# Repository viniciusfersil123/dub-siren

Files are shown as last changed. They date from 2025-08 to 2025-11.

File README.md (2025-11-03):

### Knobs (ADC)
| Function | Daisy Seed Pin | ADC Channel |
|---|---|---|
| Volume | 22 (A0) | VolumeKnob  |
| Decay | 23 (A1) | DecayKnob |
| Depth | 24 (A2) | DepthKnob |
| Tune | 25 (A3) | TuneKnob |
| Sweep | 26 (A4) | SweepKnob |
| Rate | 27 (A5) | RateKnob |

### Buttons (Digital)
| Function | Daisy Seed Pin | Notes |
|---|---|---|
| Trigger 1 | 28 (D21) | Momentary |
| Trigger 2 | 29 (D22) | Momentary |
| Trigger 3 | 30 (D23) | Momentary |
| Trigger 4 | 31 (D24) | Momentary |
| Bank Select | 32 (D25) | Toggle button |
| Sweep to Tune | 33 (D26) | Toggle button |

### LEDs
| Function | Daisy Seed Pin |
|---|---|
| Sweep LED  | D27 |
| Bank LED | D28 |
| LFO LED | D29 |

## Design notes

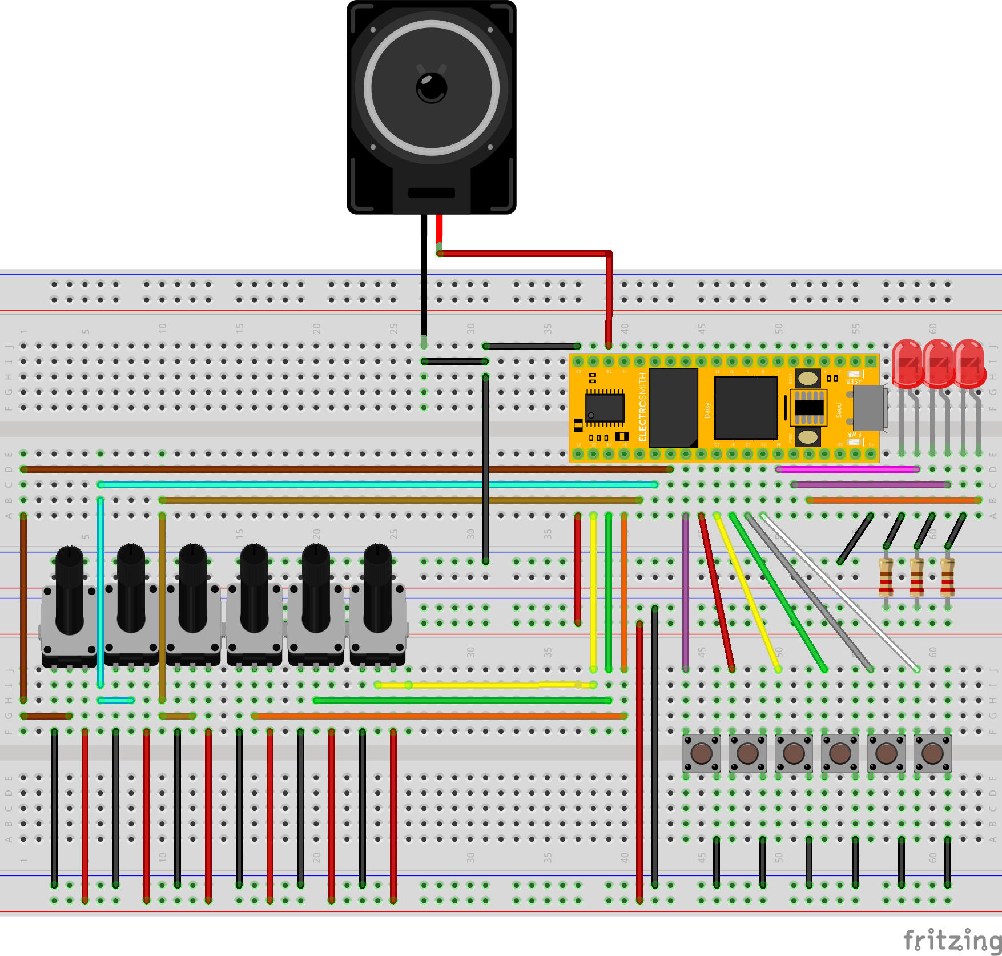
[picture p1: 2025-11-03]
assets/fritzing/dub_siren_Steckplatine.png

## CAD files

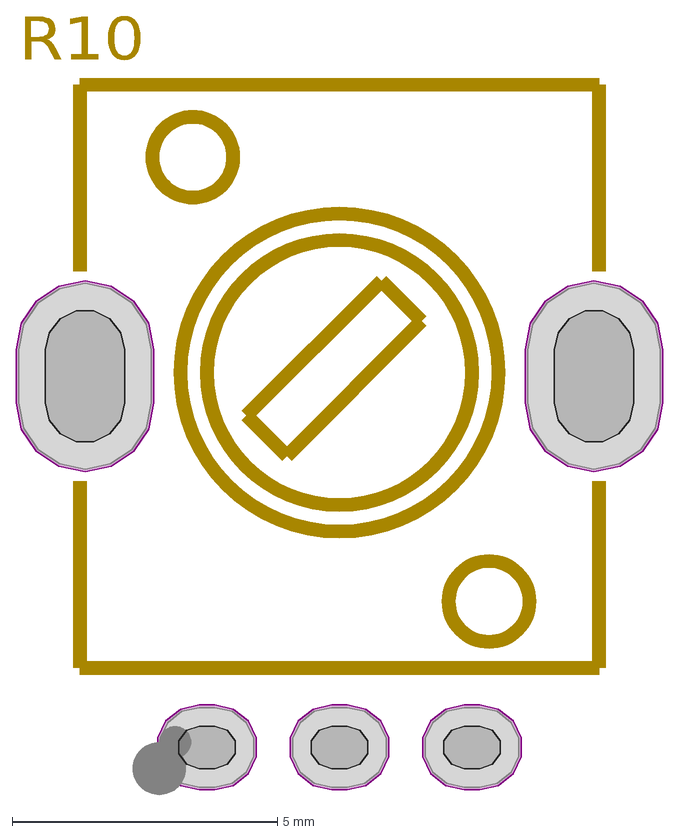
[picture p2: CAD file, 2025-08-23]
assets/footprints/potênciometro.dxf
R10

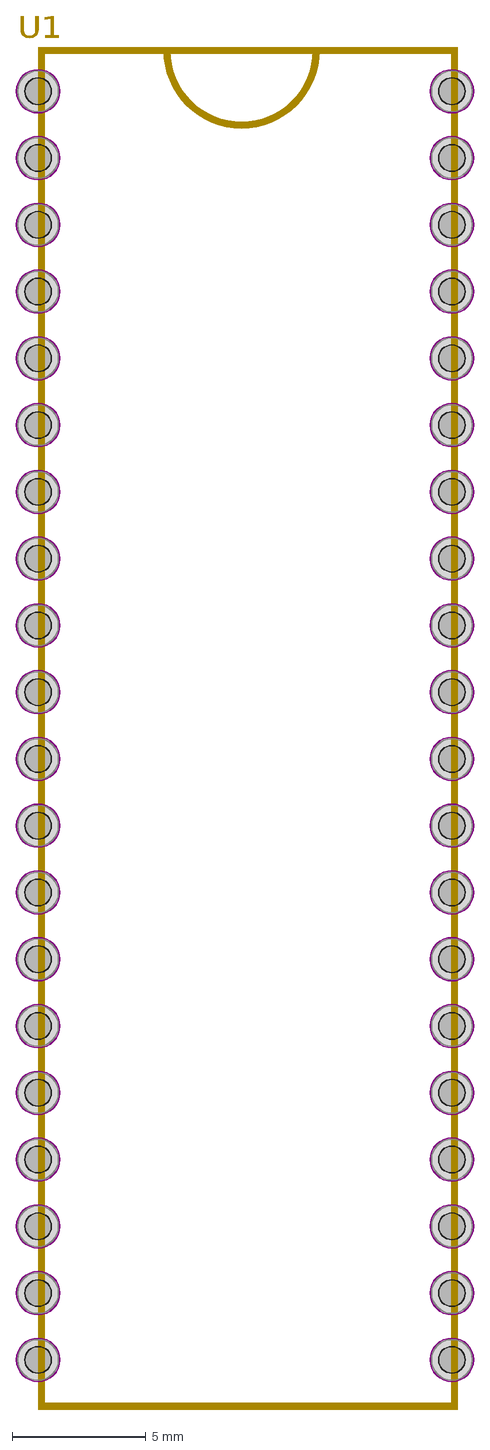
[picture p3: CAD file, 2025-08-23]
assets/footprints/ci.dxf
U1

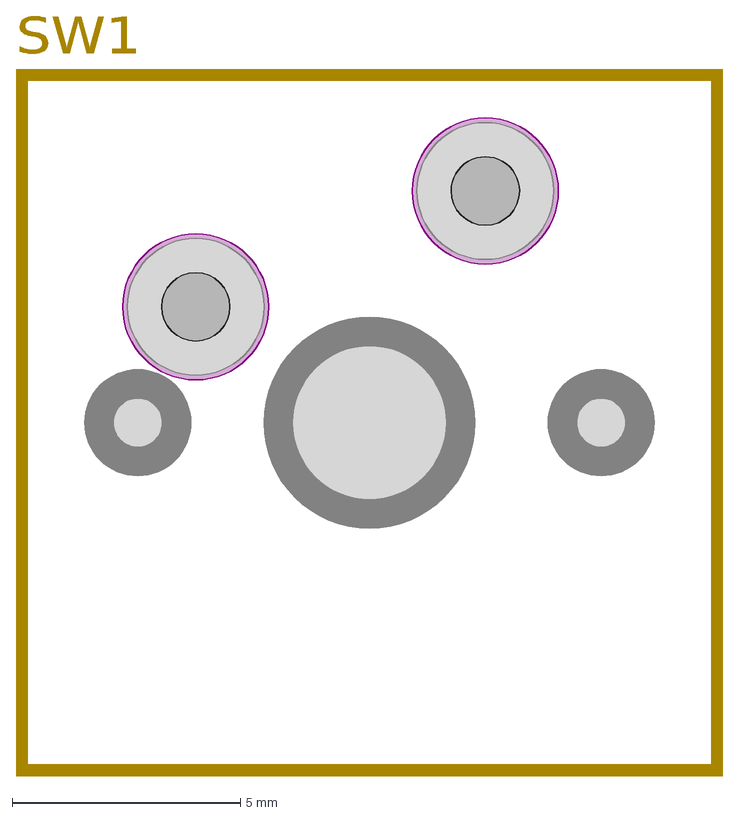
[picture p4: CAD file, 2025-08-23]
assets/footprints/botão.dxf
SW1

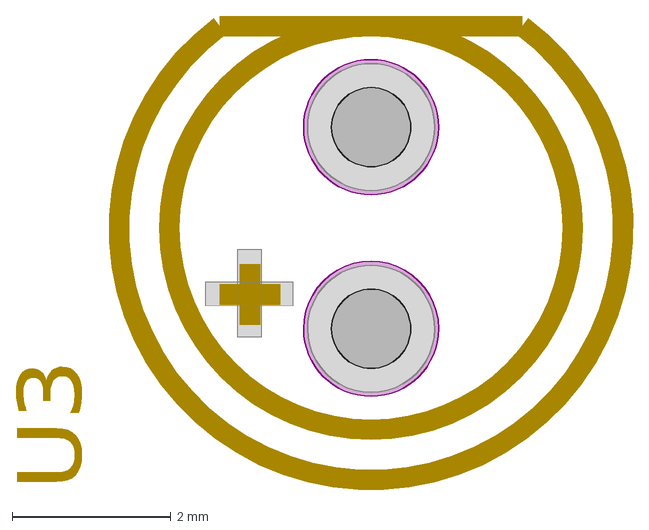
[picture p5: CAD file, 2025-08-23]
assets/footprints/led.dxf
U3

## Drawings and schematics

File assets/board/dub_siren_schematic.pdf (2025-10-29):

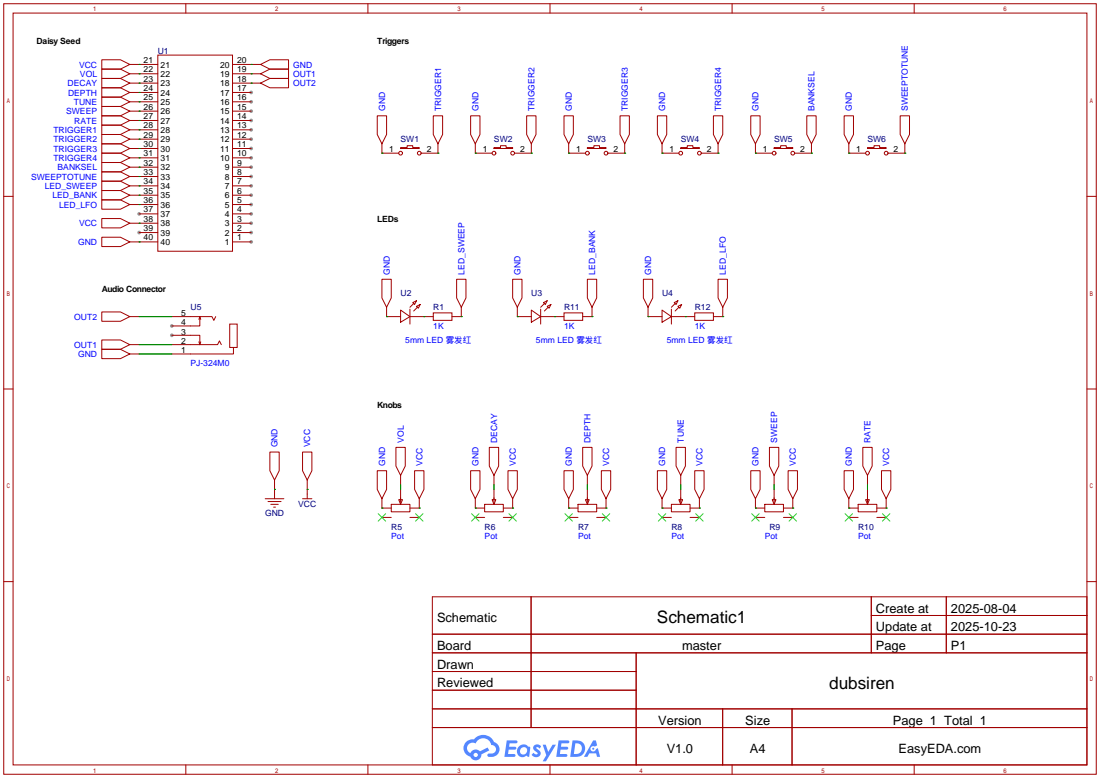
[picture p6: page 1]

Schematic | Schematic1 | Create at | 2025-08-04

Update at | 2025-10-23

Board | master | Page | P1
Drawn | | dubsiren
Reviewed

Version | Size | Page 1 Total 1
V1.0 | A4 | EasyEDA.com

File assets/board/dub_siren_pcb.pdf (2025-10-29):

# adiciona texto

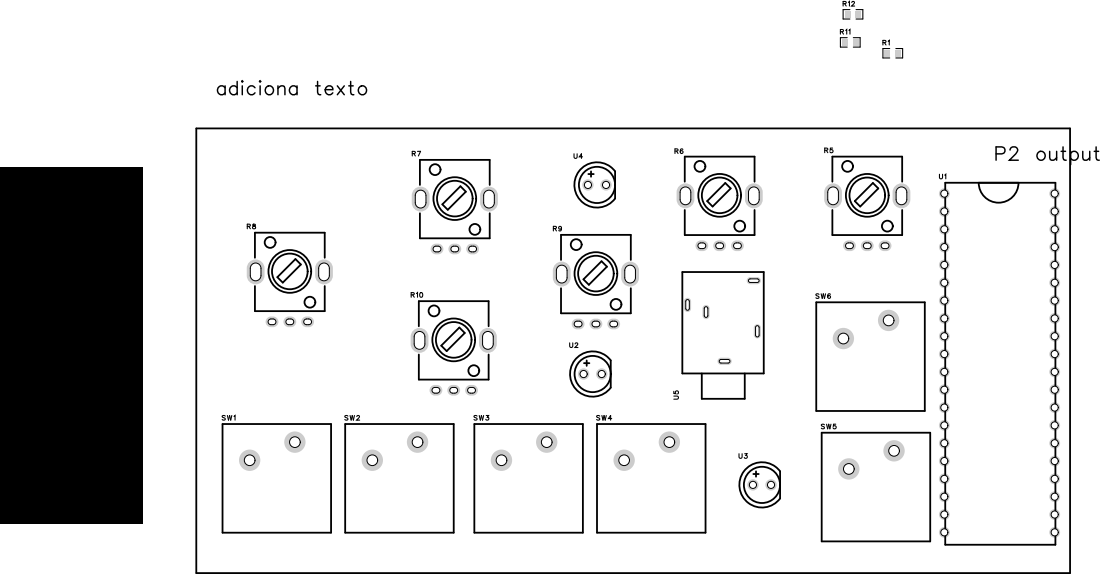
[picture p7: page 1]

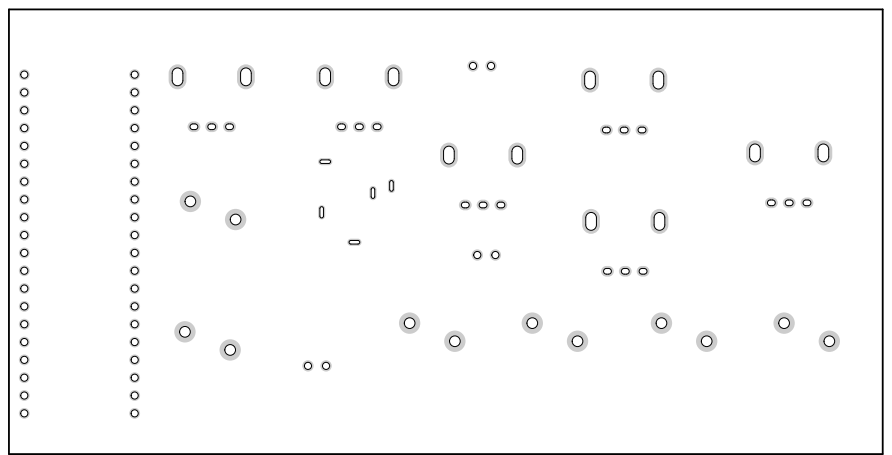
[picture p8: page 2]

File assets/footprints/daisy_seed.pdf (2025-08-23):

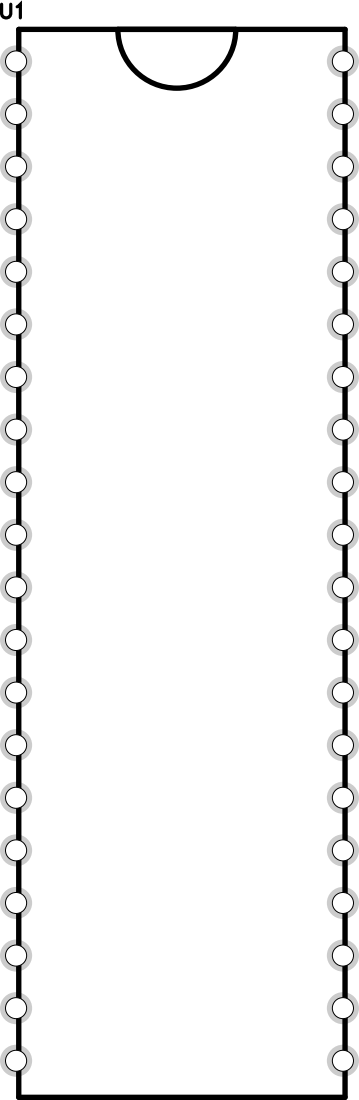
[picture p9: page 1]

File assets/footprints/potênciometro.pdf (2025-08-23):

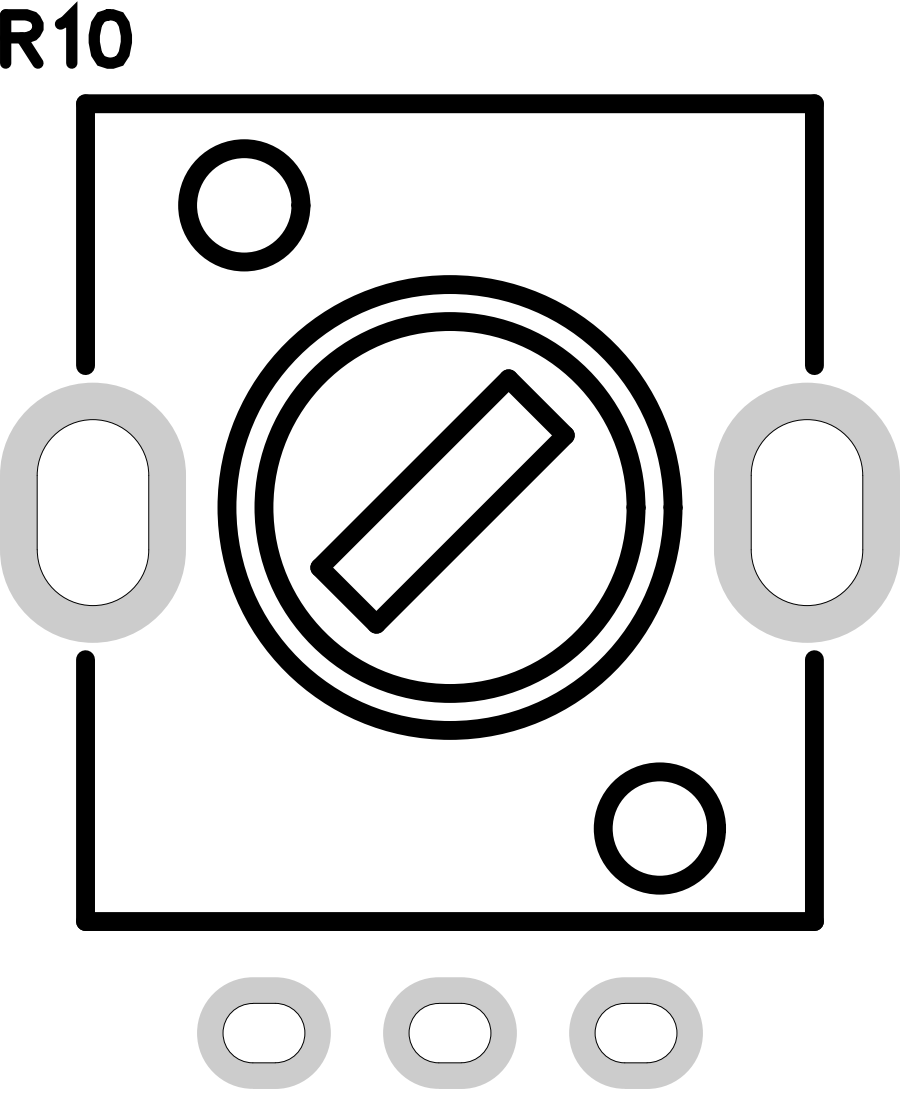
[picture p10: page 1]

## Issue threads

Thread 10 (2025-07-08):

talvez a frequência de corte no sweep a 50% seja muito baixa

haruo-gabriel, 2025-07-08:
Sinto que o sweep em 50%, flat, tem uma frequência de corte que corta demais o som do synth, parecendo estar debaixo d'água. Ao meu ver, o sweep em 50% deveria ser nossa referência principal, e deveria preservar um pouco mais dos agudos.

Para resolver isso, caso haja mudanças, seria parametrizar melhor o knob de Sweep e o espectro. Talvez logaritmicamente.

Closed 2025-07-13.

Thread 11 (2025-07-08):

lfo ainda não reinicia devidamente

haruo-gabriel, 2025-07-08:
Minha hipótese para o problema de resetar os LFOs é que o reset está sendo chamado na `AudioCallback`.

Observe abaixo que, na `AudioCallback`, há uma checagem se `triggered` é `true`:
```cpp
        // Reset envelope and LFO on trigger
        if(triggered)
        {
            lfo->ResetPhaseAll();
            envelope->Retrigger();
        }
```

Mas a variável `triggered` está sempre sendo atualizada em um clock muito mais alto na main:
```c++
    while(1)
    {
        ...
        button_handler->UpdateAll();
        ...
    }
```

Talvez a `AudioCallback` não consiga capturar sempre que um botão for pressionado.

Uma estratégia é ter uma flag que vira `true` se um trigger for pressionado, e resetá-la para `false` apenas quando a `AudioCallback` checar esse valor.

Ou seja:
```cpp
        // Reset envelope and LFO on trigger
        if(triggered_flag)
        {
            lfo->ResetPhaseAll();
            envelope->Retrigger();
            triggered_flag = false;
        }
```

Closed 2025-07-09.

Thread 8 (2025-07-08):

sweep do filtro não inicia da frequência de corte correta

haruo-gabriel, 2025-07-08:
O sweep do DS71 possui os seguintes comportamentos:

1. Knob do sweep acima de 50%
Suponha que a frequência de corte do filtro esteja em x Hz. Ao soltar um trigger, a frequência de corte deveria descer de x Hz para 20 Hz.

2. Knob do sweep abaixo de 50%
Suponha que a frequência de corte do filtro esteja em x Hz. Ao soltar um trigger, a frequência de corte deveria subir de x Hz para 20 kHz.

O que parece estar acontecendo agora:

1. Knob do sweep acima de 50%
Independente da frequência de corte, ao soltar um trigger, a frequência de corte salta para 20 kHz e caminha até 20 Hz.

2. Knob do sweep abaixo de 50%
Independente da frequência de corte, ao soltar um trigger, a frequência de corte salta para 20 Hz e caminha até 20 kHz.

O comportamento atual não é "errado", mas precisamos discutir a implementação final.

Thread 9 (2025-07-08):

o som morre com algumas combinações de parâmetros específicas

haruo-gabriel, 2025-07-08:

haruo-gabriel, 2025-07-08:
Há setups em que o som simplesmente morre ao segurar um trigger, e só é possível curar o synth ao reiniciar o daisy.

Algumas situações em que isso acontece:

- Quando o knob de Depth está em 100%

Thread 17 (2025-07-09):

som do sweep to tune gera artefatos nas frequências baixas

haruo-gabriel, 2025-07-09:
Com o 'sweep to tune' ligado, tente soltar um trigger com o pitch grave (ou seja, knob do Tune perto de 0%). Note que há artefatos (sonzinho de diarreia), e não queremos isso!

Para solucionar esse problema, é possível aplicar uma interpolação linear no pitch. Basta reutilizar a lógica de interpolação linear do envelope do VCF.

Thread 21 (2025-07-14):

adicionar região 'flat' no knob de sweep para que o sweep não atue

haruo-gabriel, 2025-07-14:
De acordo com as demos do DS71, há uma região do knob de sweep (mais especificamente na região do 50%) em que o sweep não atua no som. No DS71, essa região é marcada como 'flat'.

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

Por enquanto, não implementamos o 'flat'. É necessário delimitar o intervalo do knob de sweep em que o 'flat' atuará: [50% - delta, 50% + delta].

Closed 2025-07-25.

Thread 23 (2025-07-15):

substituir a interpolação linear do sweep da frequência de corte para interpolação exponencial

haruo-gabriel, 2025-07-15:
Assim como em #22, faz sentido implementar uma interpolação exponencial para o sweep da frequência de corte do VCF. Isto pois a frequência de corte já está sendo mapeada exponencialmente antes da fase do sweep.

Closed 2025-07-16.

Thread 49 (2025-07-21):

Desacoplar Frequência Máxima do VCO da frequência máxima aplicado pelo sweep (to tune)

viniciusfersil123, 2025-07-21:
⚠️ Lembrar de descer a frequência máxima do sweep até o limite do aliasing

viniciusfersil123, 2025-07-26:
Acho que este está resolvido com as mudanças dos limites do VCO que você fez ! Vamos falar na próxima reunião !

Closed 2025-07-28.

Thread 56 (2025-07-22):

Refatorar cálculo do `depth_exp` usando a função `pow10f` ao invés de `powf`

haruo-gabriel, 2025-07-22:
De acordo com a documentação da função `pow10f`,

> No approximation, pow10f(x) gives a 90% speed increase over powf(10.f, x)

Trocar a chamada de função
```cpp
float depth_exp = powf(10.f, (lfo->DepthValue - 1.0f));
```
para
```cpp
float depth_exp = pow10f(lfo->DepthValue - 1.0f);
```
nos dá uma pequena headroom na performance do programa.

Closed 2025-08-05.

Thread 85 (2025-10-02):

Corrigir a proporção do sweep e do decaimento quando sweep to tune está ligado

viniciusfersil123, 2025-10-02:
O filtro come o som muito rápido, seria interssante ouvir o efeito de decaimento do pitch por mais tempo quando o sweep to tune está ligado

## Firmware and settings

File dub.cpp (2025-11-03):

#include "daisy_seed.h"
#include "daisysp.h"
#include "dub.h"

/* ADCs and pin numbers (in Daisy Seed)

KNOB   | PIN NUMBER
-------------------
Volume | 22
Decay  | 23
Depth  | 24
Tune   | 25
Sweep  | 26
Rate   | 27

BUTTON      | PIN NUMBER
------------------------
Trigger 1   | 28
Trigger 2   | 29
Trigger 3   | 30
Trigger 4   | 31
BankSelect  | 32
SweepToTune | 33
*/
using namespace daisy;
using namespace daisysp;

// Daisy setup components
KnobHandlerDaisy*   knob_handler   = new KnobHandlerDaisy();
ButtonHandlerDaisy* button_handler = new ButtonHandlerDaisy();
int                 SAMPLE_RATE = 0, BLOCK_SIZE = 0;
float               output, adsr_vcf, adsr_output, vco_output, vco_modulation;
volatile bool       shouldApplyToggles = false;
std::pair<float, float> lfo_output     = std::make_pair(0, 0);

// Dub Siren components
DecayEnvelope* envelope;
Sweep*         sweep;
Triggers*      triggers;
Lfo*           lfo;
Vco*           vco;
Vcf*           vcf;
OutAmp*        out_amp;
GPIO           led_sweep;
GPIO           led_bank;
Led            led_lfo;


//Initialize led1. We'll plug it into pin 28.
//false here indicates the value is uninverted

bool DEBUG = false;


// KnobHandler functions
void KnobHandlerDaisy::InitAll()
{
    AdcChannelConfig my_adc_config[NUM_ADC_CHANNELS];
    my_adc_config[VolumeKnob].InitSingle(daisy::seed::A0);
    my_adc_config[DecayKnob].InitSingle(daisy::seed::A1);
    my_adc_config[DepthKnob].InitSingle(daisy::seed::A2);
    my_adc_config[TuneKnob].InitSingle(daisy::seed::A3);
    my_adc_config[SweepKnob].InitSingle(daisy::seed::A4);
    my_adc_config[RateKnob].InitSingle(daisy::seed::A5);
    hw.adc.Init(my_adc_config, NUM_ADC_CHANNELS);
    hw.adc.Start();
}


void KnobHandlerDaisy::UpdateAll()
{
    // VCO tune knobs
    vco->TuneValue = fclamp(hw.adc.GetFloat(TuneKnob), 0.f, 1.f);

    // Decay Envelope knobs
    envelope->ReleaseValue = fclamp(hw.adc.GetFloat(DecayKnob), 0.f, 1.f);

    // Only update sweep value while a trigger is pressed
    if(triggers->Pressed())
    {
        sweep->ReleaseValue
            = fmap(hw.adc.GetFloat(SweepKnob), 0.f, 1.f, Mapping::LINEAR);
    }

    // LFO depth (vibrato intensity 0-100%) and rate knobs
    lfo->DepthValue = fclamp(hw.adc.GetFloat(DepthKnob), 0.f, 1.f);
    lfo->RateValue  = fmap(
        hw.adc.GetFloat(RateKnob), LFO_MIN_FREQ, LFO_MAX_FREQ, Mapping::EXP);

    // OutAmp volume knob
    out_amp->VolumeValue
        = fmap(hw.adc.GetFloat(VolumeKnob), 0.f, 1.f, Mapping::EXP);
}
// KnobHandler functions


// ButtonHandler functions
void ButtonHandlerDaisy::InitAll()
{
    this->triggers[0].Init(daisy::seed::D21, 50);
    this->triggers[1].Init(daisy::seed::D22, 50);
    this->triggers[2].Init(daisy::seed::D23, 50);
    this->triggers[3].Init(daisy::seed::D24, 50);
    this->bankSelect.Init(daisy::seed::D25, 50);
    this->sweepToTune.Init(daisy::seed::D26, 50);
}

void ButtonHandlerDaisy::DebounceAll()
{
    for(int i = 0; i < 4; i++)
    {
        this->triggers[i].Debounce();
    }
    this->bankSelect.Debounce();
    this->sweepToTune.Debounce();
}

void ButtonHandlerDaisy::UpdateAll()
{
    static std::vector<int> press_stack; // pilha de botões pressionados

    for(int i = 0; i < 4; i++)
    {
        // Atualiza estados
        if(this->triggers[i].RisingEdge())
        {
            this->triggersStates[i][0] = true;
            this->triggersStates[i][1] = true;

            // Remove se já estiver na pilha e adiciona no topo
            press_stack.erase(
                std::remove(press_stack.begin(), press_stack.end(), i),
                press_stack.end());
            press_stack.push_back(i);
        }
        else if(this->triggers[i].FallingEdge())
        {
            this->triggersStates[i][2] = true;
            this->triggersStates[i][1] = false;

            // Remove da pilha
            press_stack.erase(
                std::remove(press_stack.begin(), press_stack.end(), i),
                press_stack.end());
        }
        else
        {
            this->triggersStates[i][1] = this->triggers[i].Pressed();
            this->triggersStates[i][0] = false;
            this->triggersStates[i][2] = false;
        }
    }

    // Atualiza LastIndex
    if(!press_stack.empty())
    {
        this->LastIndex = press_stack.back();
    }

    // Update toggle buttons
    if(this->bankSelect.RisingEdge())
    {
        this->bankSelectState = !this->bankSelectState;
    }

    if(this->sweepToTune.RisingEdge())
    {
        this->sweepToTuneState = !this->sweepToTuneState; // só o pendente
    }
}

// ButtonHandler functions


// Init functions
void InitComponents(int sample_rate, int block_size)
{
    triggers = new Triggers();
    envelope = new DecayEnvelope(sample_rate, block_size);
    sweep    = new Sweep(sample_rate, block_size);
    lfo      = new Lfo(sample_rate);
    vco      = new Vco(sample_rate);
    vcf      = new Vcf(sample_rate);
    out_amp  = new OutAmp();
}
// Init functions


// DecayEnvelope functions
void DecayEnvelope::SetReleaseTime(float time)
{
    this->envelope.SetTime(ADSR_SEG_RELEASE, time);
}

float DecayEnvelope::Process(bool gate)
{
    this->EnvelopeValue = this->envelope.Process(gate);
    return this->EnvelopeValue;
}


// Triggers functions
bool Triggers::Triggered()
{
    for(int i = 0; i < 4; i++)
    {
        if(button_handler->triggersStates[i][0])
            return true;
    }
    return false;
}

bool Triggers::Pressed()
{
    for(int i = 0; i < 4; i++)
    {
        if(button_handler->triggersStates[i][1])
            return true;
    }
    return false;
}

bool Triggers::Released()
{
    for(int i = 0; i < 4; i++)
    {
        if(button_handler->triggersStates[i][2])
            return true;
    }
    return false;
}

void Triggers::ClearTriggered()
{
    for(int i = 0; i < 4; i++)
    {
        if(button_handler->triggersStates[i][0])
        {
            button_handler->triggersStates[i][0] = false;
            break; // Only clear one trigger per call
        }
    }
}

// bool Triggers::IsBankSelectActive()
// {
//     return button_handler->bankSelectState;
// }
// Triggers functions


// Sweep functions
/* bool Sweep::IsSweepToTuneActive()
{
    return button_handler->sweepToTuneState;
} */

void Sweep::SetReleaseTime(float time)
{
    this->envelope.SetTime(ADSR_SEG_RELEASE, time);
}

float Sweep::Process(bool gate)
{
    this->EnvelopeValue = this->envelope.Process(gate);
    return this->EnvelopeValue;
}

float Sweep::CalculateFilterIntensity(float sweepValue)
{
    // Map sweepVal from [0,1] to [-1,1]
    float direction = 2.0f * (sweepValue - 0.5f);
    float abs_dir   = fabsf(direction);

    // Dead zone threshold
    float threshold = DEADZONE_HALF_WIDTH;
    float intensity = 0.0f;

    // Assymetrical curve
    // Faster sweep for values below threshold - attack effect
    // Slower sweep for values above threshold - decay effect
    if(direction > threshold)
    {
        intensity
            = 0.5f * powf((abs_dir - threshold) / (1.0f - threshold), 2.0f);
    }
    else if(direction < -threshold)
    {
        intensity
            = 2.f * powf((abs_dir - threshold) / (1.0f - threshold), 0.5f);
        // intensity = 3.f;
    }
    // If sweep is in the threshold interval, maintain 0.

    return intensity;
}

float Sweep::CalculateVcoIntensity(float sweepValue)
{
    // Map sweepVal from [0,1] to [-1,1]
    float direction = 2.0f * (sweepValue - 0.5f);
    float abs_dir   = fabsf(direction);

    float threshold = DEADZONE_HALF_WIDTH;
    float intensity = 0.f;

    // Calculate sweep intensity for VCO:
    if(direction > threshold)
    {
        intensity
            = 0.75f * powf((abs_dir - threshold) / (1.0f - threshold), 2.0f);
    }
    else if(direction < -threshold)
    {
        intensity
            = 0.75f * powf((abs_dir - threshold) / (1.0f - threshold), 2.0f);
    }
    // If sweep is in the threshold interval, maintain 0.

    return intensity;
}

float Sweep::UpdateCutoffFreq(float sweepValue, Vcf* vcf, float adsrOutput)
{
    float base_exp = vcf->CutoffExponent;

    // Map sweepVal from [0,1] to [-1,1]
    float direction = 2.0f * (sweepValue - 0.5f);

    // Get filter intensity using the dedicated method
    float intensity = this->CalculateFilterIntensity(sweepValue);

    // Compute target exponent:
    // direction < 0 → freq goes up   → end_exp = 1
    // direction > 0 → freq goes down → end_exp = 0
    float end_exp = 0.5f - 0.5f * direction;

    // Blend start and end exponents modulated by ADSR and sweep intensity
    float sweep_exp
        = base_exp + (end_exp - base_exp) * (1.0f - adsrOutput) * intensity;

    // Final exponential frequency
    return VCF_MIN_FREQ * powf(VCF_MAX_FREQ / VCF_MIN_FREQ, sweep_exp);
}

// --- Lfo functions ---
void Lfo::UpdateWaveforms(int index, bool bankB)
{
    if(bankB)
    {
        switch(index)
        {
            case 0:
                osc[0].SetWaveform(Oscillator::WAVE_SIN);
                osc_harm[0].SetWaveform(Oscillator::WAVE_SIN);
                break;
            case 1:
                osc[1].SetWaveform(Oscillator::WAVE_SQUARE);
                osc_harm[1].SetWaveform(Oscillator::WAVE_SQUARE);
                break;
            case 2:
                osc[2].SetWaveform(Oscillator::WAVE_SQUARE);
                osc_harm[2].SetWaveform(Oscillator::WAVE_SAW);
                break;
            case 3:
                osc[3].SetWaveform(Oscillator::WAVE_RAMP);
                osc_harm[3].SetWaveform(Oscillator::WAVE_RAMP);
                break;
        }
    }
    else
    {
        static constexpr int waves[4] = {Oscillator::WAVE_SIN,
                                         Oscillator::WAVE_SQUARE,
                                         Oscillator::WAVE_SAW,
                                         Oscillator::WAVE_RAMP};

        osc[index].SetWaveform(waves[index]);
    }
}

float Lfo::MixLfoSignals(int index, bool bankB)
{
    float base = osc[index].Process();
    float harm = osc_harm[index].Process();

    if(bankB)
    {
        switch(index)
        {
            case 0: return 0.5f * (base + harm);        // sin + sin(3x)
            case 1: return 0.5f * (base + harm);        // square + square(4x)
            case 2: return 0.5f * (base + harm);        // square + saw(4x)
            case 3: return 0.5f * (base + 0.5f * harm); // ramp + 0.5*ramp(2x)
        }
    }

    return base;
}


void Lfo::SetAmpAll(float amp)
{
    for(int i = 0; i < 4; i++)
    {
        this->osc[i].SetAmp(amp);
    }
}

void Lfo::SetFreqAll(float freq)
{
    static constexpr float harm_ratios[4] = {4.0f, 8.0f, 8.0f, 2.0f};

    for(int i = 0; i < 4; i++)
    {
        osc[i].SetFreq(freq);
        osc_harm[i].SetFreq(freq * harm_ratios[i]);
    }
}


void Lfo::ResetPhaseAll()
{
    for(int i = 0; i < 4; i++)
    {
        this->osc[i].Reset(0.0f);
        this->osc_harm[i].Reset(0.0f);
    }
}

std::pair<float, float> Lfo::ProcessAll()
{
    int index = button_handler->LastIndex;
    // Use o banco atualmente ativo
    bool bankB = button_handler->currentBankState;

    // Nova seleção → inicia crossfade
    if(index != currIndex)
    {
        prevIndex    = currIndex;
        currIndex    = index;
        fadeProgress = 0.0f;
    }

    fadeProgress = fminf(fadeProgress + fadeRate, 1.0f);

    float out = 0.0f;

    if(currIndex >= 0)
    {
        UpdateWaveforms(currIndex, bankB);
        out += MixLfoSignals(currIndex, bankB) * fadeProgress;
    }

    if(prevIndex >= 0 && fadeProgress < 1.0f)
    {
        UpdateWaveforms(prevIndex, bankB);
        out += MixLfoSignals(prevIndex, bankB) * (1.0f - fadeProgress);
    }

    // Convert LFO output to modulation signal [0,1]
    // No longer scaling by DepthValue here - FM ratio handles this now
    float modsig = 0.5f + out;

    return std::make_pair(out, modsig);
}

// --- Lfo functions ---


// Vco functions
void Vco::SetFreq(float freq)
{
    this->osc.SetFreq(freq);
}

float Vco::Process()
{
    return this->osc.Process();
}

float Vco::CalculateFMFreq(float carrier_freq, float lfo_bipolar, float depth)
{
    // FM synthesis: M = C / R (Modulator freq = Carrier freq / Ratio)
    float modulator_freq = carrier_freq / this->fm_ratio;

    // Calculate deviation: D = I * M, where I is controlled by depth
    float fm_index  = LFO_FM_INDEX * depth;
    float deviation = fm_index * modulator_freq;

    // Apply LFO modulation with FM deviation scaling
    float frequency_shift = lfo_bipolar * deviation;

    // Calculate modulated frequency
    float freq = carrier_freq + frequency_shift;

    // --- Frequency folding ---
    // Fold negative frequencies to positive (spectral mirroring at 0 Hz)
    freq = fabsf(freq);

    // Fold frequencies above Nyquist back down (spectral mirroring at Nyquist limit)
    if(freq > this->nyquist_limit)
    {
        freq = 2.0f * this->nyquist_limit - freq;
        freq = fabsf(freq); // Handle double-folding for extreme cases
    }

    return freq;
}
// Vco functions


// Vcf functions
void Vcf::SetFreq(float freq)
{
    // Svf filter accepts frequency up to SAMPLE_RATE / 3
    float limited_freq = fclamp(freq, VCF_MIN_FREQ, SAMPLE_RATE / 4);
    this->filter.SetFreq(limited_freq);
}

void Vcf::UpdateCutoffPressed(float sweepValue)
{
    // Map the sweep value to achieve:
    // 0% to 50% knob  -> 0% to firstHalfMax% frequency range (exponential)
    // 50% to 100% knob -> firstHalfMax% to 100% frequency range (exponential)
    const float firstHalfMax = 0.9f;

    if(sweepValue <= 0.5f)
    {
        // First half: Exponential mapping to firstHalfMax of range
        float       normalized = sweepValue * 2.f; // 0.0 to 1.0
        const float expCurve
            = 0.5f; // 0.1 makes the curve more linear in the end
        this->CutoffExponent = firstHalfMax * powf(normalized, expCurve);
    }
    else
    {
        // Second half: Power function for smooth compression
        float normalized = (sweepValue - 0.5f) * 2.f; // 0.0 to 1.0
        float remaining  = 1.0f - firstHalfMax;
        this->CutoffExponent
            = firstHalfMax + remaining * powf(normalized, SWEEP_CURVE_POWER);
    }

    this->CutoffFreq
        = VCF_MIN_FREQ
          * powf(VCF_MAX_FREQ / VCF_MIN_FREQ, this->CutoffExponent);
    this->SetFreq(this->CutoffFreq);
}

float Vcf::Process(float in)
{
    this->filter.Process(in);
    return this->filter.Low(); // Return low-pass output
}
// Vcf functions


// OutAmp functions
void OutAmp::SetVolume(float volume)
{
    this->VolumeValue = volume;
}

float OutAmp::Process(float in)
{
    return in * this->VolumeValue;
}
// OutAmp functions


// Debug functions
void PrintKnobValues()
{
    // Raw input values
    hw.Print("Volume: " FLT_FMT3, FLT_VAR3(hw.adc.GetFloat(VolumeKnob)));
    hw.Print("   Decay:  " FLT_FMT3, FLT_VAR3(hw.adc.GetFloat(DecayKnob)));
    hw.Print("   Depth:  " FLT_FMT3, FLT_VAR3(hw.adc.GetFloat(DepthKnob)));
    hw.PrintLine("");
    hw.Print("Tune:   " FLT_FMT3, FLT_VAR3(hw.adc.GetFloat(TuneKnob)));
    hw.Print("   Sweep:  " FLT_FMT3, FLT_VAR3(hw.adc.GetFloat(SweepKnob)));
    hw.Print("   Rate:   " FLT_FMT3, FLT_VAR3(hw.adc.GetFloat(RateKnob)));
    hw.PrintLine("");

    // Class attribute values
    // hw.Print("Volume: " FLT_FMT3, FLT_VAR3(out_amp->VolumeValue));
    // hw.Print("   Decay:  " FLT_FMT3, FLT_VAR3(envelope->ReleaseValue));
    // hw.Print("   Depth:  " FLT_FMT3, FLT_VAR3(lfo->DepthValue));
    // hw.PrintLine("");
    // hw.Print("Tune:   " FLT_FMT3, FLT_VAR3(vco->TuneValue));
    // hw.Print("   Sweep:  " FLT_FMT3, FLT_VAR3(sweep->SweepValue));
    // hw.Print("   Rate:   " FLT_FMT3, FLT_VAR3(lfo->RateValue));
    // hw.PrintLine("");
}

void PrintButtonStates()
{
    for(int i = 0; i < 4; i++)
    {
        hw.Print("Trigger %d: %d %d %d | ",
                 i + 1,
                 button_handler->triggers[i].RisingEdge(),
                 button_handler->triggers[i].Pressed(),
                 button_handler->triggers[i].FallingEdge());
    }
    hw.PrintLine("");
}

void PrintOutputs()
{
    hw.PrintLine("ADSR: " FLT_FMT3 " | LFO: " FLT_FMT3 " " FLT_FMT3
                 " | VCO: " FLT_FMT3,
                 FLT_VAR3(adsr_output),
                 FLT_VAR3(lfo_output.first),
                 FLT_VAR3(lfo_output.first),
                 FLT_VAR3(vco_output));
}
// Debug functions


// Main functions
void AudioCallback(AudioHandle::InputBuffer  in,
                   AudioHandle::OutputBuffer out,
                   size_t                    size)
{
    if(shouldApplyToggles)
    {
        lfo->ResetPhaseAll();

        button_handler->currentBankState  = button_handler->bankSelectState;
        button_handler->sweepToTuneActive = button_handler->sweepToTuneState;

        triggers->ClearTriggered();
        shouldApplyToggles = false;
    }

    for(size_t i = 0; i < size; i++)
    {
        bool pressed = triggers->Pressed();

        // Use frozen sweep value after release
        float sweepVal = sweep->ReleaseValue;


        // Reset envelope and LFO on trigger
        if(shouldApplyToggles)
        {
            lfo->ResetPhaseAll();

            // Aplicar mudanças pendentes
            button_handler->currentBankState = button_handler->bankSelectState;
            button_handler->sweepToTuneActive
                = button_handler->sweepToTuneState;
            triggers->ClearTriggered();
            shouldApplyToggles = false;
        }

        // Set and process envelope
        envelope->SetReleaseTime(
            ADSR_MIN_RELEASE_TIME
            + (envelope->ReleaseValue
               * (ADSR_RELEASE_TIME - ADSR_MIN_RELEASE_TIME)));
        adsr_output = envelope->Process(pressed);

        // --- Filter frequency (VCF) logic ---
        if(pressed)
        {
            vcf->UpdateCutoffPressed(sweepVal);
        }
        else
        {
            vcf->CutoffFreq
                = sweep->UpdateCutoffFreq(sweepVal, vcf, adsr_output);
            vcf->SetFreq(vcf->CutoffFreq);
        }


        // Initial output from envelope
        output = adsr_output;

        // --- LFO processing ---
        lfo->SetFreqAll(lfo->RateValue);
        lfo->SetAmpAll(
            1.0f); // LFO at full amplitude, FM ratio will scale deviation
        lfo_output = lfo->ProcessAll();

        // --- VCO frequency and modulation with FM-inspired deviation ---
        // Calculate base carrier frequency from tune knob
        float carrier_freq
            = VCO_MIN_FREQ * powf(VCO_MAX_FREQ / VCO_MIN_FREQ, vco->TuneValue);

        // Convert LFO output from [0,1] to [-1,+1]
        float lfo_bipolar = (lfo_output.second - 0.5f) * 2.0f;

        // FM synthesis: depth controls intensity, ratio stored in VCO
        float vco_freq
            = vco->CalculateFMFreq(carrier_freq, lfo_bipolar, lfo->DepthValue);

        // Optional sweep modulation mapped to VCO frequency
        if(button_handler->sweepToTuneActive)
        {
            float direction = 2.0f * (sweepVal - 0.5f);

            // Get VCO intensity using the dedicated method
            float intensity = sweep->CalculateVcoIntensity(sweepVal);

            float end_exp   = 0.5f - 0.5f * direction;
            float sweep_exp = vco->TuneValue
                              + (end_exp - vco->TuneValue)
                                    * (1.0f - adsr_output) * intensity;

            // Recalculate carrier with sweep, then apply FM modulation
            carrier_freq
                = VCO_MIN_FREQ * powf(VCO_MAX_FREQ / VCO_MIN_FREQ, sweep_exp);

            // Recalculate with swept carrier frequency
            vco_freq = vco->CalculateFMFreq(
                carrier_freq, lfo_bipolar, lfo->DepthValue);
        }


        vco->SetFreq(vco_freq);
        vco_output = vco->Process();
        output *= vco_output;

        // -- LFO LED control ---
        led_lfo.Set((lfo_output.first * 0.5f + 0.5f) * adsr_output);

        led_lfo.Update();

        // --- Apply VCF low-pass filter ---
        output = vcf->Process(output);

        // --- Apply output amplifier ---
        output = out_amp->Process(output);

        // --- Send to output buffer (stereo) ---
        out[0][i] = output;
        out[1][i] = output;
    }
}

int main(void)
{
    hw.Init();
    hw.SetAudioBlockSize(4);
    hw.SetAudioSampleRate(SaiHandle::Config::SampleRate::SAI_48KHZ);
    SAMPLE_RATE = hw.AudioSampleRate();
    BLOCK_SIZE  = hw.AudioBlockSize();
    led_sweep.Init(daisy::seed::D27, GPIO::Mode::OUTPUT);
    led_bank.Init(daisy::seed::D28, GPIO::Mode::OUTPUT);
    led_lfo.Init(daisy::seed::D29, false, SAMPLE_RATE);
    knob_handler->InitAll();
    button_handler->InitAll();
    InitComponents(SAMPLE_RATE, BLOCK_SIZE);

    if(DEBUG)
    {
        hw.StartLog(true);
        hw.PrintLine("Daisy Dub Siren");
    }

    hw.StartAudio(AudioCallback);

    while(1)
    {
        knob_handler->UpdateAll();
        button_handler->DebounceAll();
        button_handler->UpdateAll();
        led_sweep.Write(button_handler->sweepToTuneState);
        led_bank.Write(button_handler->bankSelectState);

        if(triggers->Triggered())
        {
            shouldApplyToggles = true;
        }

        if(DEBUG)
        {
            System::Delay(10);
        }
    }
}

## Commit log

2025-02-26 adds button
2025-02-27 feat: implement vcf lowpass filter in knob A6 (removed lfoButton1 functionalities)
2025-03-10 feat: add SweepToTuneButton class and integrate button handling in EnvelopeGenerator
2025-04-16 feat: reset phase all
    [dub.cpp]
2025-07-01 muda filtro onepole para svf, linter com prettier
2025-07-03 primeira porra de implementação de sweep do filtro funcionando
2025-07-04 primeira implementação completa do sweep to tune com hardware - led e botão
2025-07-04 adicione hardware para seleção de banco de ondas
2025-07-05 arruma trigger de reinicio de fase de LFO
2025-07-06 implementa dummy de banco B
2025-07-06 primeira implementação trevosa do segundo banco de LFO
2025-07-07 implementação bela do banco B de LFOs
2025-07-09 adiciona variável de debug DEBUG em dub.cpp
    As funções de debug na main, que estavam comentadas, agora estão descomentadas e dentro de
    uma condicional que avalia o booleano DEBUG. Basta mudar DEBUG de false
    para true.
2025-07-09 reset de fase dos osciladores funciona
    [dub.cpp]
2025-07-09 corrige o comportamento da frequência de corte e sweep
    [dub.cpp]
2025-07-15 refina interpolação linear no sweep do tune para interpolar o expoente
2025-07-16 agrupando mudanças das issues #17, #19, #23 (dependentes)
    Alterações no cálculo do depth e DC offset, cálculo do pitch e do sweep - todas dependentes entre si.
    [dub.cpp]
2025-07-16 remapeia volume de linear para exponencial
2025-07-16 muda mapeamento do rate para exponencial
2025-07-16 resolve conflito de rebase manualmente
    [dub.cpp]
2025-07-17 adiciona led para visualização do lfo
2025-07-17 primeira implementação da curva quadrática para controle de sweep
2025-07-22 altera as frequências mínima e máxima do VCO para midi C1 e C7
2025-07-26 remove atuação do knob de sweep após soltar o trigger
2025-07-26 modifica lógica para estado do banco de lfos
2025-07-27 adiciona lógica para ativar sweeptotune apena no próximo acionamento do trigger
2025-07-27 implementa estrutura de fila para lidar com estados dos triggers
2025-07-27 adiciona crossfade entre lfos para transição suave
2025-07-27 diminui valor da macro da cutoff mínima do VCO de 120Hz para 5Hz
2025-07-27 reajusta valor da macro da cutoff mínima do VCO de 5Hz para 15Hz
2025-07-29 remove trigger para remover clicks
2025-08-02 Refatora cálculo do depth_exp usando a função pow10f ao invés de powf
2025-08-10 adiciona assets fritzing
    [dub_siren.fzz]
2025-08-13 ♻️ move variável CutoffFreq da classe Sweep para classe Vcf
2025-08-16 ♻️ encapsula lógica da CutoffFreq da AudioCallback em funções das classes Vcf e Sweep
2025-08-16 ✨ altera mapeamento da função Vcf::UpdateCutoffPressed para linear por partes
2025-08-20 ♻️ adiciona `fclamp` nas leituras de knobs na função `UpdateAll`
2025-08-23 arruma conexões do led no arquivo fritzing
    [dub_siren.fzz]
2025-08-23 arruma conexões do dac e ground
    [dub_siren.fzz]
2025-08-23 adiciona footprint
    [botão.dxf, ci.dxf, led.dxf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]
2025-08-23 arruma typo
    [botão.dxf, ci.dxf, led.dxf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]
2025-09-04 💡 corrige a documentação dos pin numbers para os knobs e botões
    [dub.cpp]
2025-10-10 ♻️ refatora processamento do LFO e VCO usando estratégia de FM com index, ratio e folding de frequência em casos extremos
2025-10-15 remapeia Decay de linear para exponencial
2025-10-15 aumenta o tempo de decay para 40s
2025-10-15 ♻️ adiciona funções dedicadas para o cálculo da intensidade do sweep para o filtro e VCO na classe Sweep
2025-10-23 adiciona jack de audio
2025-10-23 remapeia Decay de exponencial para linear de volta
2025-10-23 diminui tempo de decay para 15s
2025-10-28 ♻️ refatora threshold hardcoded por constante DEADZONE_HALF_WIDTH na classe Sweep
2025-10-28 🔧 diminui DEADZONE_HALF_WIDTH de 0.2f para 0.1f
